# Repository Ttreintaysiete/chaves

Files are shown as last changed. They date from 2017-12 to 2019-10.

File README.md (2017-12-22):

# chaves
Cheap Hacky Audio/Video - Glitch VGA synth based on jonasbers.com/chav/

This is a WIP, and PCBs have not fully tested, if you want to contribute send a build to your favorite pcb provider and give us any feedback.

Pending...

* will generate a bom
* building guide

## Chaves

Its a glitch video synth bassed on CHA/V as stated, but with lots of controls and patcheable pins with the intentions of doing a mini-modular video glitch synth.

Like in the original CHA/V it has 6 VCOs, with selectables ranges, sync sources, frequency and effects outputs (thanks to the coupling caps). Here is a schematic of a single voice

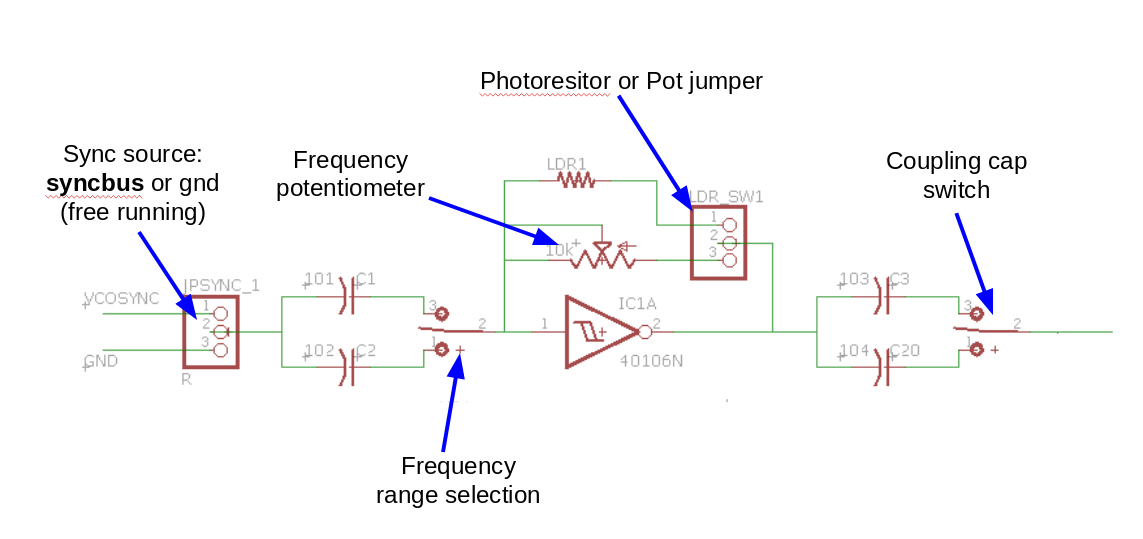
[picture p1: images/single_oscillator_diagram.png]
single oscillator schematic


* The __syncbus__ can be either connected to the vsyn or hsync of the VGA tester. This will send the selected sync to the jumperpins near the beggining of the Oscillator so you can either select each oscillator to be connected to this sync bus or not to be free running.
* Since we are using pinheaders you can use patcables from any point of the pcb so anthoer oscillator can __modulate__ the sync of a specific oscillator...
* Every voice output can be connected to any of the RGA VGA inputs with patchables, or can be patched somewhere else, to create complex patterns

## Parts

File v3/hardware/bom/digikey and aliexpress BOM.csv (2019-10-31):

description | qty | digikey | notes
9x 3×2 pin header row | 9 | 2057-PH2-06-UA-ND
2x 4×1 pin header row | 2 | PH1-04-UA
2x 1×12 pin header row | 2 | 2057-PH1-12-UA-ND
1x 1×9 pin header row | 1 | 2057-2PH1-09-UA-ND
2x blue LED | 2
4x 100K resistors (R6, R7, R9, R10) | 4 | https://www.digikey.ca/product-detail/en/stackpole-electronics-inc/CF14JT100K/CF14JT100KCT-ND/1830399
6x 1k resistors (R1, R2, R3, R4, R5, R8) | 6 | https://www.digikey.ca/product-detail/en/stackpole-electronics-inc/CF14JT1K00/CF14JT1K00CT-ND/1830350
2x BC547 npn transistor | 2 | BC547BTA
1x 4001 rectifier diode (D2) | 1 |  | optional
12x 4.7mm pitch spdt slide toggle switches (if you use flip-style instead, keep in mind that the pins will be inverted) | 12
6x 100k linear PC mount potentiometers | 6 | https://www.aliexpress.com/item/32986513037.html | choose 100k option
1x 40106 hex Schmitt IC | 1 | CD40106BE
1x 14-pin IC socket | 1
3x PJ302m 3.5mm jacks | 3 | https://www.aliexpress.com/item/32766726918.html | or (100 qty) | https://www.aliexpress.com/item/32765941321.html
2x LDR, a.k.a. photo-resistors (LDR1, LDR2) | 2 | https://www.digikey.ca/products/en/sensors-transducers/optical-sensors-photo-detectors-cds-cells/540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
11x (or more) 2.54mm closed jumpers | 11 | S9337-ND
10x (or more) 200mm socket-to-socket style jumper wires | 10 | 1568-1513-ND
4x 10uf electrolytic capacitors (C5, C15, C11, C23) negative leg should be pointing down. check oscillator 2 in the picture above. this part is not a joke: they could potentially explode if you put them in backwards. | 4 | https://www.digikey.ca/product-detail/en/panasonic-electronic-components/ECA-1HM100I/P10425CT-ND/8603345
4x 1uF ceramic capacitors (C4, C14, C10, C22) | 4 | FG28X5R1H105KRT06 | search if you want other footprints
13x 0.1 uF ceramic capacitors (C2, C20, C7, C17, C9, C21, C13, C25, C19) | 13 | SR215C104KAR
4x 0.01 uF ceramic capacitors (C3, C16, C18, C24) | 4 | K103K10X7RF5UH5
4x 1000 pF ceramic capacitors (C1, C6, C8, C12) | 4 | BC5111-ND

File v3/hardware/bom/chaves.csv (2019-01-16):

Qty | Value | Device | Package | Parts | Description
1 |  | DCBARRELPTH | DCJACK_2MM_PTH | CN1 | 2.0mm DC Barrel Jack
2 |  | LED5MM | LED5MM | LED1, LED2 | LED
8 |  | PINHD-1X1 | 1X01 | +5V, BJ, GJ, JGND, JHSYNC, JVCC1, JVSYNC, RJ | Pin header 1x1 for 0.1 spacing"
2 |  | PINHD-1X12-CB | 1X12-CB | O13, O45 | PIN HEADER
2 |  | PINHD-1X4 | 1X04 | JP2, JP13 | PIN HEADER
1 |  | PINHD-1X9 | 1X09-BIG | JP1 | Pin header 1x10 0.1 spacing"
9 |  | PINHD-2X3 | 2X03 | BLUE, GREEN, JP3, JP8, JP9, JP10, JP11, JP12, RED | PIN HEADER
2 |  | R-US_0204/2V | 0204V | LDR1, LDR2 | RESISTOR, American symbol
4 | 100k | R-US_0204/2V | 0204V | R6, R7, R9, R10 | RESISTOR, American symbol
4 | 101 | C-US050-025X075 | C050-025X075 | C1, C4, C10, C12 | CAPACITOR, American symbol
2 | 102 | C-US050-025X075 | C050-025X075 | C2, C5 | CAPACITOR, American symbol
8 | 103 | C-US050-025X075 | C050-025X075 | C3, C6, C8, C14, C16, C18, C22, C24 | CAPACITOR, American symbol
11 | 104 | C-US050-025X075 | C050-025X075 | C7, C9, C11, C13, C15, C17, C19, C20, C21, C23, C25 | CAPACITOR, American symbol
6 | 10k | POT_USVERTICAL | ALPS_POT_VERTICAL | POT1, POT2, POT3, POT4, POT5, POT6
1 | 1N4004 | 1N4004 | DO41-10 | D2 | DIODE
6 | 1k | R-US_0204/2V | 0204V | R1, R2, R3, R4, R5, R8 | RESISTOR, American symbol
1 | 40106N | 40106N | DIL14 | IC1 | Hex SCHMITT TRIGGER
3 | PJ302M | PJ302M | PJ302M | JIN1, JIN2, JIN3 | PJ302M horizontal / right angled mount 3.5 mm jack socket
12 | T-80-T-SPDT-ON-OFF-ON | T-80-T-SPDT-ON-OFF-ON | M9040P | U$1, U$2, U$3, U$4, U$5, U$6, U$7, U$8, U$9, U$10, U$11, U$12
2 | bc547 | -NPN-TO92-ECB | TO92-ECB | T1, T2 | NPN Transistror

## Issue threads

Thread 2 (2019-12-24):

Simultaneous audio and video output?

VicVID, 2019-12-24:
Hi - I am unsure if I am using the 9-pin header for the 3.5m output jacks correctly.  At present, I can out put audio OR video but not together.

Please advise!

Thanks

Vic   email:  randomaxe@cox.net

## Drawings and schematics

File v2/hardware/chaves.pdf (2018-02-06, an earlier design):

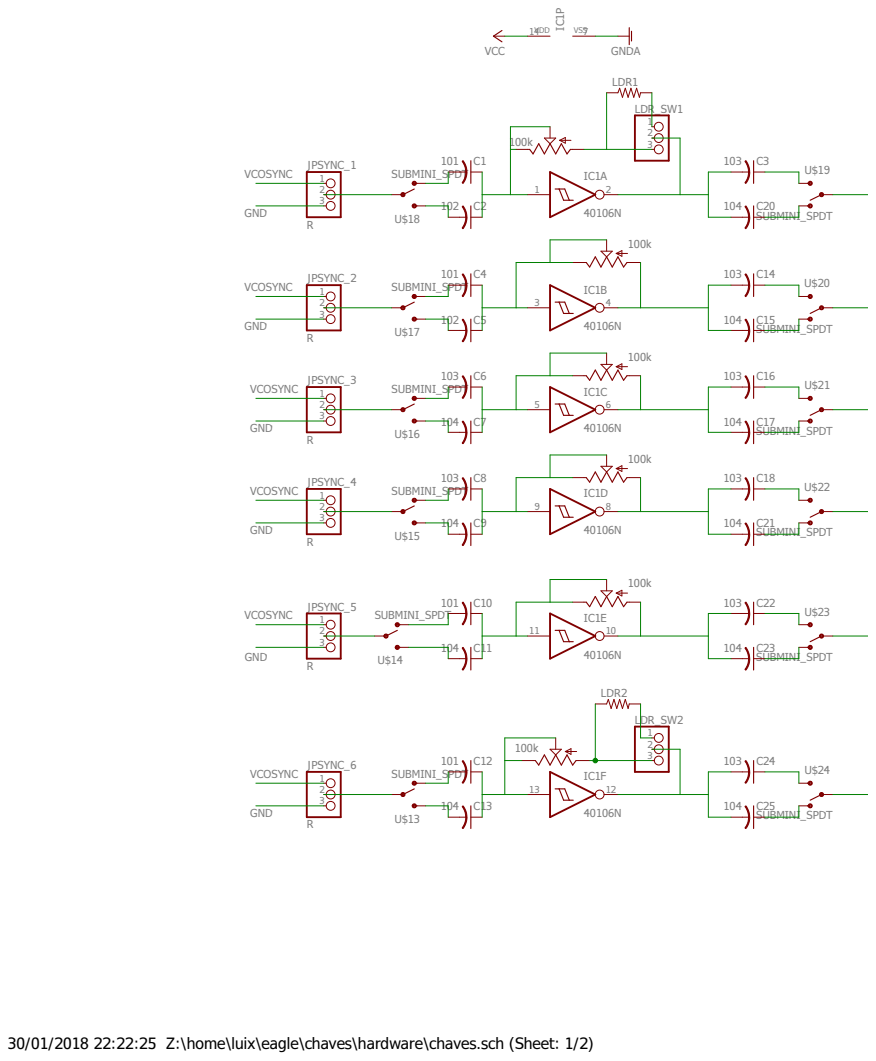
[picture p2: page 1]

30/01/2018 22:22:25 Z:\home\luix\eagle\chaves\hardware\chaves.sch (Sheet: 1/2)

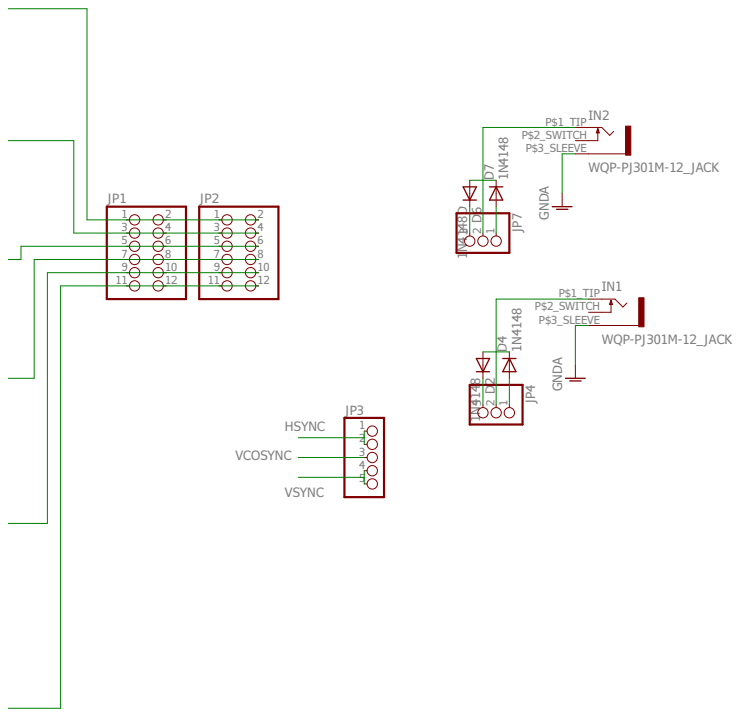
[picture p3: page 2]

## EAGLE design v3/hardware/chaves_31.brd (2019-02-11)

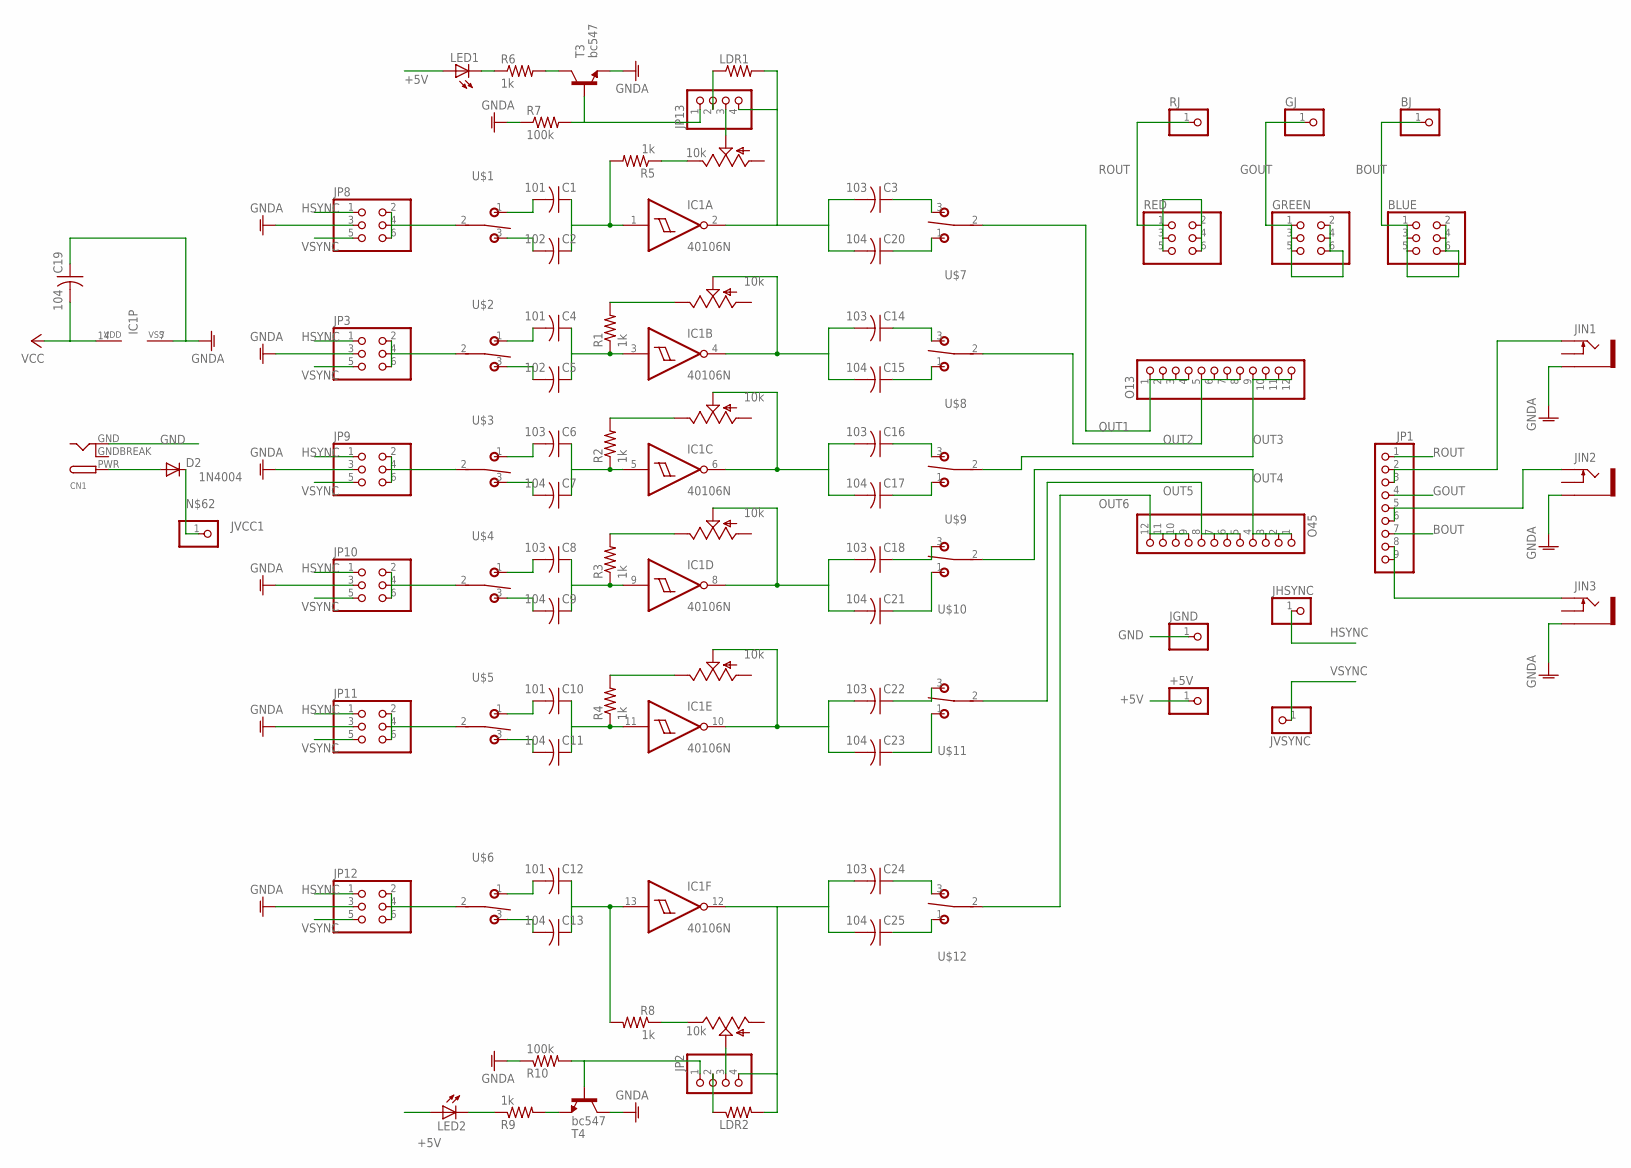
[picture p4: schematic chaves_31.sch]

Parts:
+5V: PINHD-1X1; 1X01
BJ: PINHD-1X1; 1X01
BLUE: PINHD-2X3; 2X03
C1, C4, C10, C12: 101; C050-025X075
C2, C5: 102; C050-025X075
C3, C6, C8, C14, C16, C18, C22, C24: 103; C050-025X075
C7, C9, C11, C13, C15, C17, C19, C20, C21, C23, C25: 104; C050-025X075
CN1: DCBARRELPTH; DCJACK_2MM_PTH
D2: 1N4004; DO41-10
GJ: PINHD-1X1; 1X01
GREEN: PINHD-2X3; 2X03
IC1: 40106N; DIL14
JGND: PINHD-1X1; 1X01
JHSYNC: PINHD-1X1; 1X01
JIN1, JIN2, JIN3: PJ302M
JP1: PINHD-1X9; 1X09-BIG
JP2, JP13: PINHD-1X4; 1X04
JP3, JP8, JP9, JP10, JP11, JP12: PINHD-2X3; 2X03
JVCC1: PINHD-1X1; 1X01
JVSYNC: PINHD-1X1; 1X01
LDR1, LDR2: R-US_0204/2V; 0204V
LED1, LED2: LED5MM
O13, O45: PINHD-1X12-CB; 1X12-CB
POT1, POT2, POT3, POT4, POT5, POT6: 10k; ALPS_POT_VERTICAL
R1, R2, R3, R4, R5, R6, R8, R9: 1k; 0204V
R7, R10: 100k; 0204V
RED: PINHD-2X3; 2X03
RJ: PINHD-1X1; 1X01
T3, T4: bc547; TO92-CBE
U$1, U$2, U$3, U$4, U$5, U$6, U$7, U$8, U$9, U$10, U$11, U$12: T-80-T-SPDT-ON-OFF-ON; M9040P

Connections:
+5V: +5V.1, C19.2, IC1.14 (VDD), LED1.A, LED2.A
BOUT: BJ.1, BLUE.1, BLUE.2, BLUE.3, BLUE.4, BLUE.5, BLUE.6, JP1.7
GND: C19.1, CN1.GND, IC1.7 (VSS), JGND.1, JIN1.GND (SLEEVE), JIN2.GND (SLEEVE), JIN3.GND (SLEEVE), JP3.3, JP8.3, JP9.3, JP10.3, JP11.3, JP12.3, R7.1, R10.1, T3.E, T4.C
GNDBREAK: CN1.GNDBREAK
GOUT: GJ.1, GREEN.1, GREEN.2, GREEN.3, GREEN.4, GREEN.5, GREEN.6, JP1.4
HSYNC: JHSYNC.1, JP3.1, JP8.1, JP9.1, JP10.1, JP11.1, JP12.1
unnamed: C1.2, U$1.1 (O)
unnamed: C2.2, U$1.3 (S)
unnamed: JP13.2, LDR1.1
unnamed: C5.2, U$2.3 (S)
unnamed: C4.2, U$2.1 (O)
unnamed: JP13.3, POT1.P$2 (S)
unnamed: C8.2, U$4.1 (O)
unnamed: C9.2, U$4.3 (S)
unnamed: JIN1.TIP, JP1.2, JP1.3
unnamed: C6.2, U$3.1 (O)
unnamed: C7.2, U$3.3 (S)
unnamed: JIN2.TIP, JP1.5, JP1.6
unnamed: JIN3.TIP, JP1.8, JP1.9
unnamed: JP3.2, JP3.4, JP3.6, U$2.2
unnamed: R6.2, T3.C
unnamed: C20.1, U$7.1 (O)
unnamed: C3.1, U$7.3 (S)
unnamed: LED1.K (C), R6.1
unnamed: POT1.P$1 (E), R5.1
unnamed: JP8.2, JP8.4, JP8.6, U$1.2
unnamed: LED2.K (C), R9.1
unnamed: POT2.P$1 (E), R1.2
unnamed: JP9.2, JP9.4, JP9.6, U$3.2
unnamed: C15.1, U$8.1 (O)
unnamed: R9.2, T4.E
unnamed: C14.1, U$8.3 (S)
unnamed: C17.1, U$9.1 (O)
unnamed: C16.1, U$9.3 (S)
unnamed: JP10.2, JP10.4, JP10.6, U$4.2
unnamed: JP13.1, R7.2, T3.B
unnamed: POT3.P$1 (E), R2.2
unnamed: JP11.2, JP11.4, JP11.6, U$5.2
unnamed: JP12.2, JP12.4, JP12.6, U$6.2
unnamed: C21.1, U$10.1 (O)
unnamed: C18.1, U$10.3 (S)
unnamed: C23.1, U$11.1 (O)
unnamed: C22.1, U$11.3 (S)
unnamed: C25.1, U$12.1 (O)
unnamed: C24.1, U$12.3 (S)
unnamed: C10.2, U$5.1 (O)
unnamed: POT4.P$1 (E), R3.2
unnamed: C11.2, U$5.3 (S)
unnamed: C13.2, U$6.3 (S)
unnamed: C12.2, U$6.1 (O)
unnamed: POT5.P$1 (E), R4.2
unnamed: C24.2, C25.2, IC1.12 (O), JP2.4, LDR2.2
unnamed: JP2.2, LDR2.1
unnamed: JP2.3, POT6.P$2 (S)
unnamed: POT6.P$1 (E), R8.1
unnamed: JP2.1, R10.2, T4.B
unnamed: D2.C, JVCC1.1
unnamed: C3.2, C20.2, IC1.2 (O), JP13.4, LDR1.2
unnamed: C14.2, C15.2, IC1.4 (O), POT2.P$2 (S)
unnamed: C16.2, C17.2, IC1.6 (O), POT3.P$2 (S)
unnamed: C18.2, C21.2, IC1.8 (O), POT4.P$2 (S)
unnamed: C22.2, C23.2, IC1.10 (O), POT5.P$2 (S)
OUT1: O13.1, O13.2, O13.3, O13.4, U$7.2
OUT2: O13.5, O13.6, O13.7, O13.8, U$8.2
OUT3: O13.9, O13.10, O13.11, O13.12, U$9.2
OUT4: O45.1, O45.2, O45.3, O45.4, U$10.2
OUT5: O45.5, O45.6, O45.7, O45.8, U$11.2
OUT6: O45.9, O45.10, O45.11, O45.12, U$12.2
ROUT: JP1.1, RED.1, RED.2, RED.3, RED.4, RED.5, RED.6, RJ.1
SS1: C1.1, C2.1, IC1.1 (I), R5.2
SS2: C4.1, C5.1, IC1.3 (I), R1.1
SS3: C6.1, C7.1, IC1.5 (I), R2.1
SS4: C8.1, C9.1, IC1.9 (I), R3.1
SS5: C10.1, C11.1, IC1.11 (I), R4.1
SS6: C12.1, C13.1, IC1.13 (I), R8.2
VIN: CN1.PWR, D2.A
VSYNC: JP3.5, JP8.5, JP9.5, JP10.5, JP11.5, JP12.5, JVSYNC.1

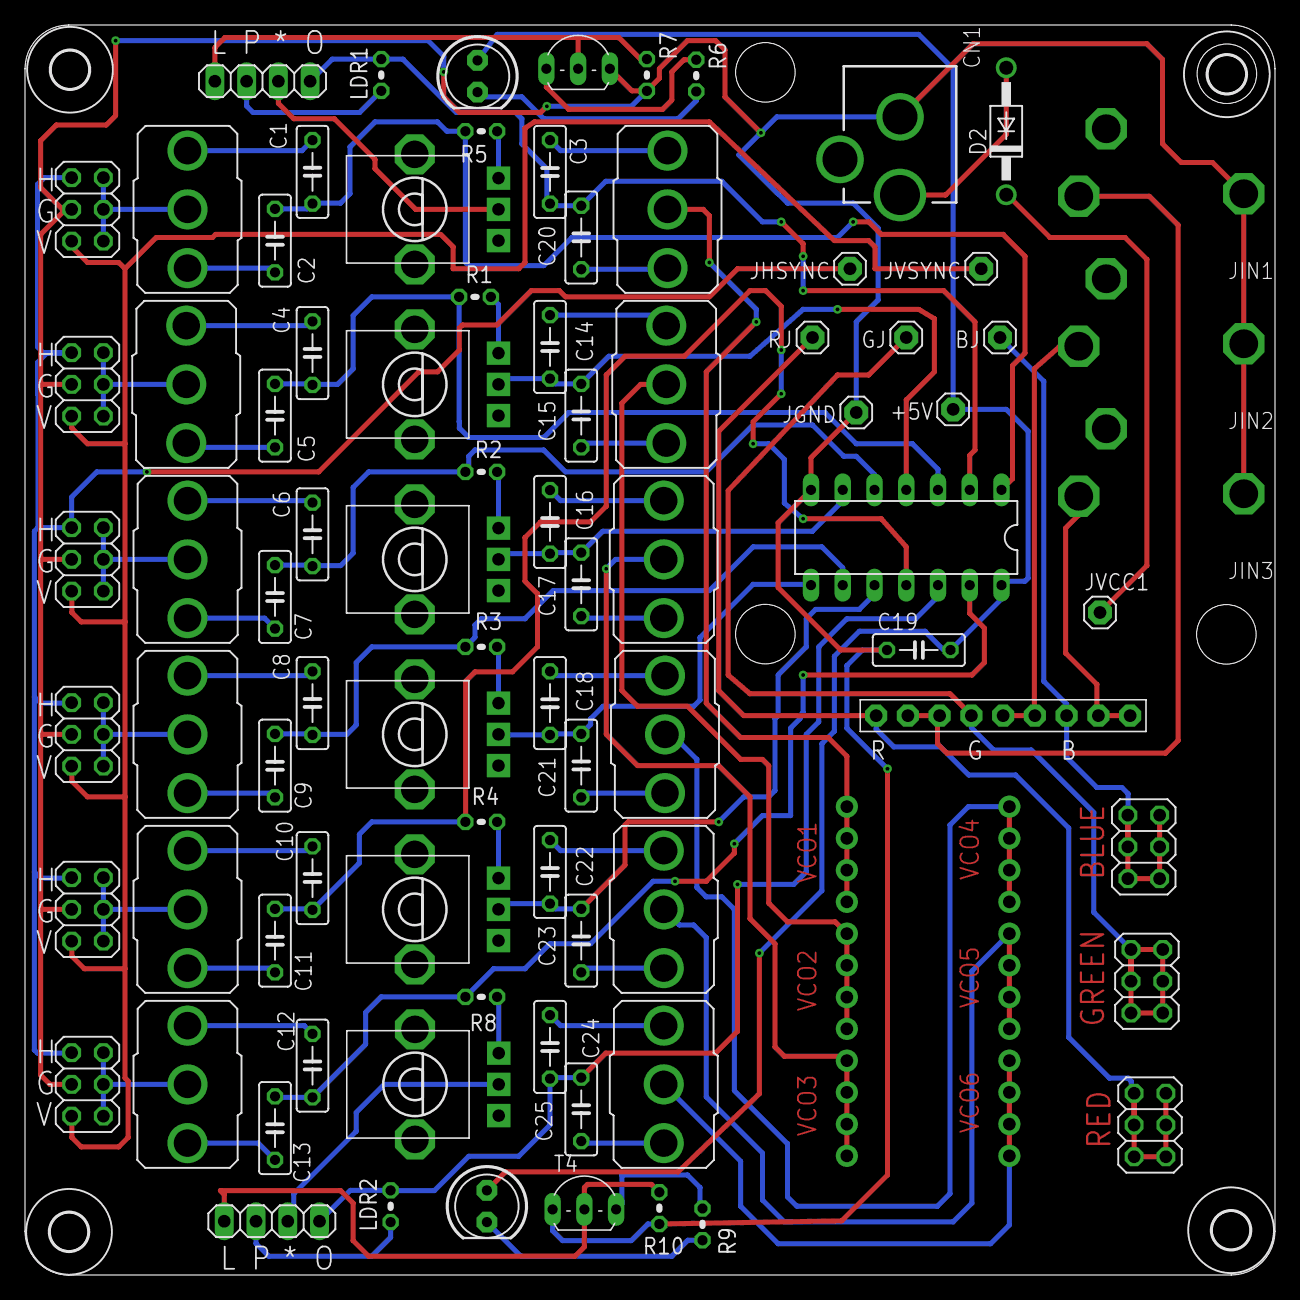
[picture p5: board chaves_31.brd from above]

Board: 2 copper layers, 100.0 x 100.0 mm, 95 parts (0 on the bottom side), 76 nets.

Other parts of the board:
E$1, E$2, E$3, E$4: DRILL_0.1875
E$5, E$6, E$7, E$8: 3,0

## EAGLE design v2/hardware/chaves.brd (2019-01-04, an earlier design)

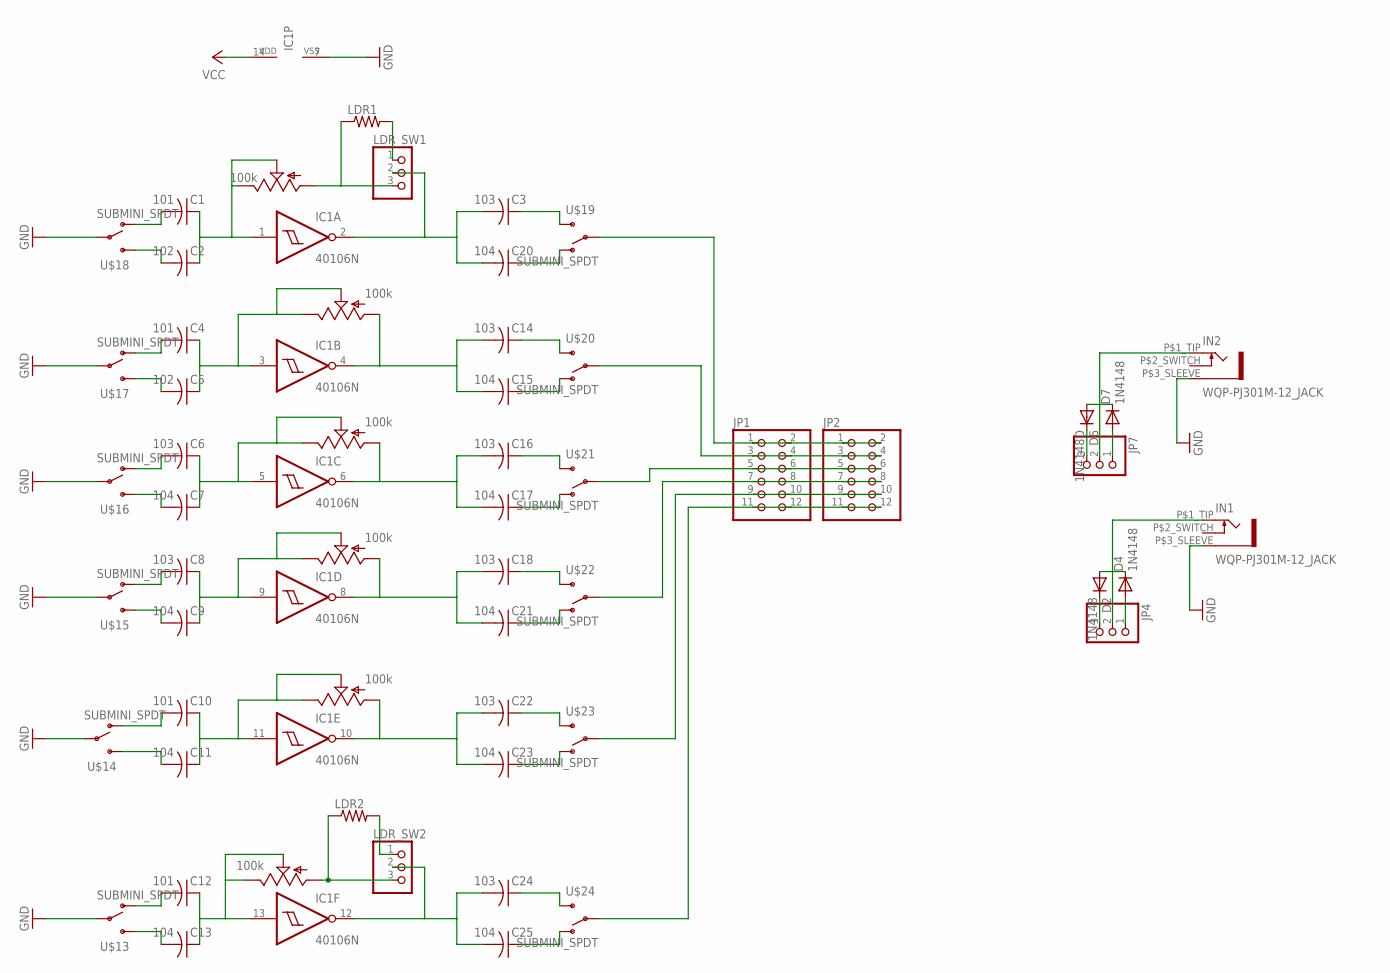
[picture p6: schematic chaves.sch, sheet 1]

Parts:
C1, C4, C10, C12: 101; C050-025X075
C2, C5: 102; C050-025X075
C3, C6, C8, C14, C16, C18, C22, C24: 103; C050-025X075
C7, C9, C11, C13, C15, C17, C20, C21, C23, C25: 104; C050-025X075
D2, D4, D7: 1N4148; DO35-7
D6: 1N4148D; DO35-7
IC1: 40106N; DIL14
IN1, IN2: WQP-PJ301M-12_JACK
JP1, JP2: PINHD-2X6; 2X06
JP4, JP7: PINHD-1X3CB; 1X03-CLEANBIG
LDR1, LDR2: R-US_0204/7; 0204/7
LDR_SW1, LDR_SW2: PINHD-1X3; 1X03
POT1, POT2, POT3, POT4, POT5, POT6: 100k; ALPS_POT_VERTICAL
U$13, U$14, U$15, U$16, U$17, U$18, U$19, U$20, U$21, U$22, U$23, U$24: SUBMINI_SPDT; SUBMINI_TOGGLE

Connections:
GND: IC1.7 (VSS), IN1.P$3_SLEEVE (1), IN2.P$3_SLEEVE (1), U$13.COM (COMMON), U$14.COM (COMMON), U$15.COM (COMMON), U$16.COM (COMMON), U$17.COM (COMMON), U$18.COM (COMMON); also elsewhere on the board
GND1: C3.2, C20.2, IC1.2 (O), LDR_SW1.2
GND2: C14.2, C15.2, IC1.4 (O), POT2.P$3 (A)
GND3: C16.2, C17.2, IC1.6 (O), POT3.P$3 (A)
GND4: C18.2, C21.2, IC1.8 (O), POT4.P$3 (A)
GND5: C22.2, C23.2, IC1.10 (O), POT5.P$3 (A)
GND6: C24.2, C25.2, IC1.12 (O), LDR_SW2.2
unnamed: C1.2, U$18.1 (O)
unnamed: C2.2, U$18.3 (S)
unnamed: LDR2.2, LDR_SW2.1
unnamed: C5.2, U$17.3 (S)
unnamed: C4.2, U$17.1 (O)
unnamed: LDR1.2, LDR_SW1.1
unnamed: C8.2, U$15.1 (O)
unnamed: C9.2, U$15.3 (S)
unnamed: D6.A, D7.C, IN2.P$1_TIP (2), JP7.2
unnamed: C6.2, U$16.1 (O)
unnamed: C7.2, U$16.3 (S)
unnamed: C20.1, U$19.1 (O)
unnamed: C3.1, U$19.3 (S)
unnamed: JP1.1, JP1.2, JP2.1, JP2.2, U$19.COM (COMMON)
unnamed: LDR1.1, LDR_SW1.3, POT1.P$3 (A)
unnamed: LDR2.1, LDR_SW2.3, POT6.P$3 (A)
unnamed: D2.A, D4.C, IN1.P$1_TIP (2), JP4.2
unnamed: C15.1, U$20.1 (O)
unnamed: C14.1, U$20.3 (S)
unnamed: JP1.3, JP1.4, JP2.3, JP2.4, U$20.COM (COMMON)
unnamed: C17.1, U$21.1 (O)
unnamed: C16.1, U$21.3 (S)
unnamed: JP1.5, JP1.6, JP2.5, JP2.6, U$21.COM (COMMON)
unnamed: C1.1, C2.1, IC1.1 (I), POT1.P$1 (E), POT1.P$2 (S)
unnamed: C4.1, C5.1, IC1.3 (I), POT2.P$1 (E), POT2.P$2 (S)
unnamed: C6.1, C7.1, IC1.5 (I), POT3.P$1 (E), POT3.P$2 (S)
unnamed: C8.1, C9.1, IC1.9 (I), POT4.P$1 (E), POT4.P$2 (S)
unnamed: C21.1, U$22.1 (O)
unnamed: C18.1, U$22.3 (S)
unnamed: JP1.7, JP1.8, JP2.7, JP2.8, U$22.COM (COMMON)
unnamed: C23.1, U$23.1 (O)
unnamed: C22.1, U$23.3 (S)
unnamed: JP1.9, JP1.10, JP2.9, JP2.10, U$23.COM (COMMON)
unnamed: C25.1, U$24.1 (O)
unnamed: C24.1, U$24.3 (S)
unnamed: JP1.11, JP1.12, JP2.11, JP2.12, U$24.COM (COMMON)
unnamed: C10.2, U$14.1 (O)
unnamed: C10.1, C11.1, IC1.11 (I), POT5.P$1 (E), POT5.P$2 (S)
unnamed: C11.2, U$14.3 (S)
unnamed: C13.2, U$13.3 (S)
unnamed: C12.2, U$13.1 (O)
unnamed: C12.1, C13.1, IC1.13 (I), POT6.P$1 (E), POT6.P$2 (S)
unnamed: D2.C, JP4.3
unnamed: D4.A, JP4.1
unnamed: D6.C, JP7.3
unnamed: D7.A, JP7.1
VCC: IC1.14 (VDD); also elsewhere on the board

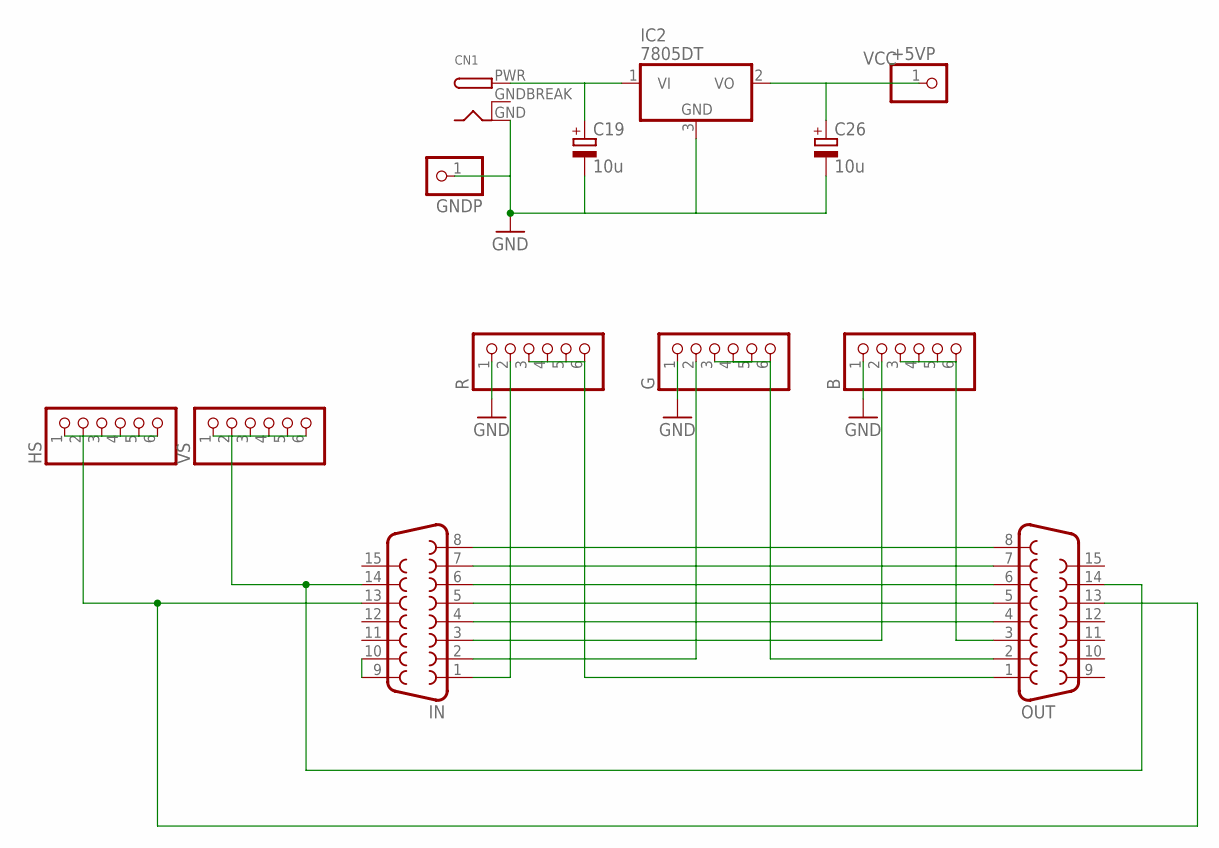
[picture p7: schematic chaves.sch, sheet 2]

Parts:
+5VP: PINHD-1X1CB; 1X01-CLEANBIG
B: PINHD-1X6CLEAN; 1X06-CLEAN
C19, C26: 10u; E2,5-5
CN1: DCBARRELPTH; DCJACK_2MM_PTH
G: PINHD-1X6CLEAN; 1X06-CLEAN
GNDP: PINHD-1X1CB; 1X01-CLEANBIG
HS: PINHD-1X6CLEAN; 1X06-CLEAN
IC2: 7805DT; TO252
IN: F15HDH; HDF15H
OUT: F15HDH; HDF15H
R: PINHD-1X6CLEAN; 1X06-CLEAN
VS: PINHD-1X6CLEAN; 1X06-CLEAN

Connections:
GND: B.1, C19.-, C26.-, CN1.GND, G.1, GNDP.1, IC2.3 (GND), IN.4, IN.5, IN.6, IN.7, IN.8, IN.9, IN.10, OUT.4, OUT.5, OUT.6, OUT.7, OUT.8, R.1; also elsewhere on the board
GNDBREAK: CN1.GNDBREAK
unnamed: IN.1, R.2
unnamed: OUT.1, R.3, R.4, R.5, R.6
unnamed: G.2, IN.2
unnamed: G.3, G.4, G.5, G.6, OUT.2
unnamed: B.2, IN.3
unnamed: B.3, B.4, B.5, B.6, OUT.3
unnamed: IN.14, OUT.14, VS.1, VS.2, VS.3, VS.4, VS.5, VS.6
unnamed: HS.1, HS.2, HS.3, HS.4, HS.5, HS.6, IN.13, OUT.13
unnamed: C19.+, CN1.PWR, IC2.1 (VI)
VCC: +5VP.1, C26.+, IC2.2 (VO); also elsewhere on the board

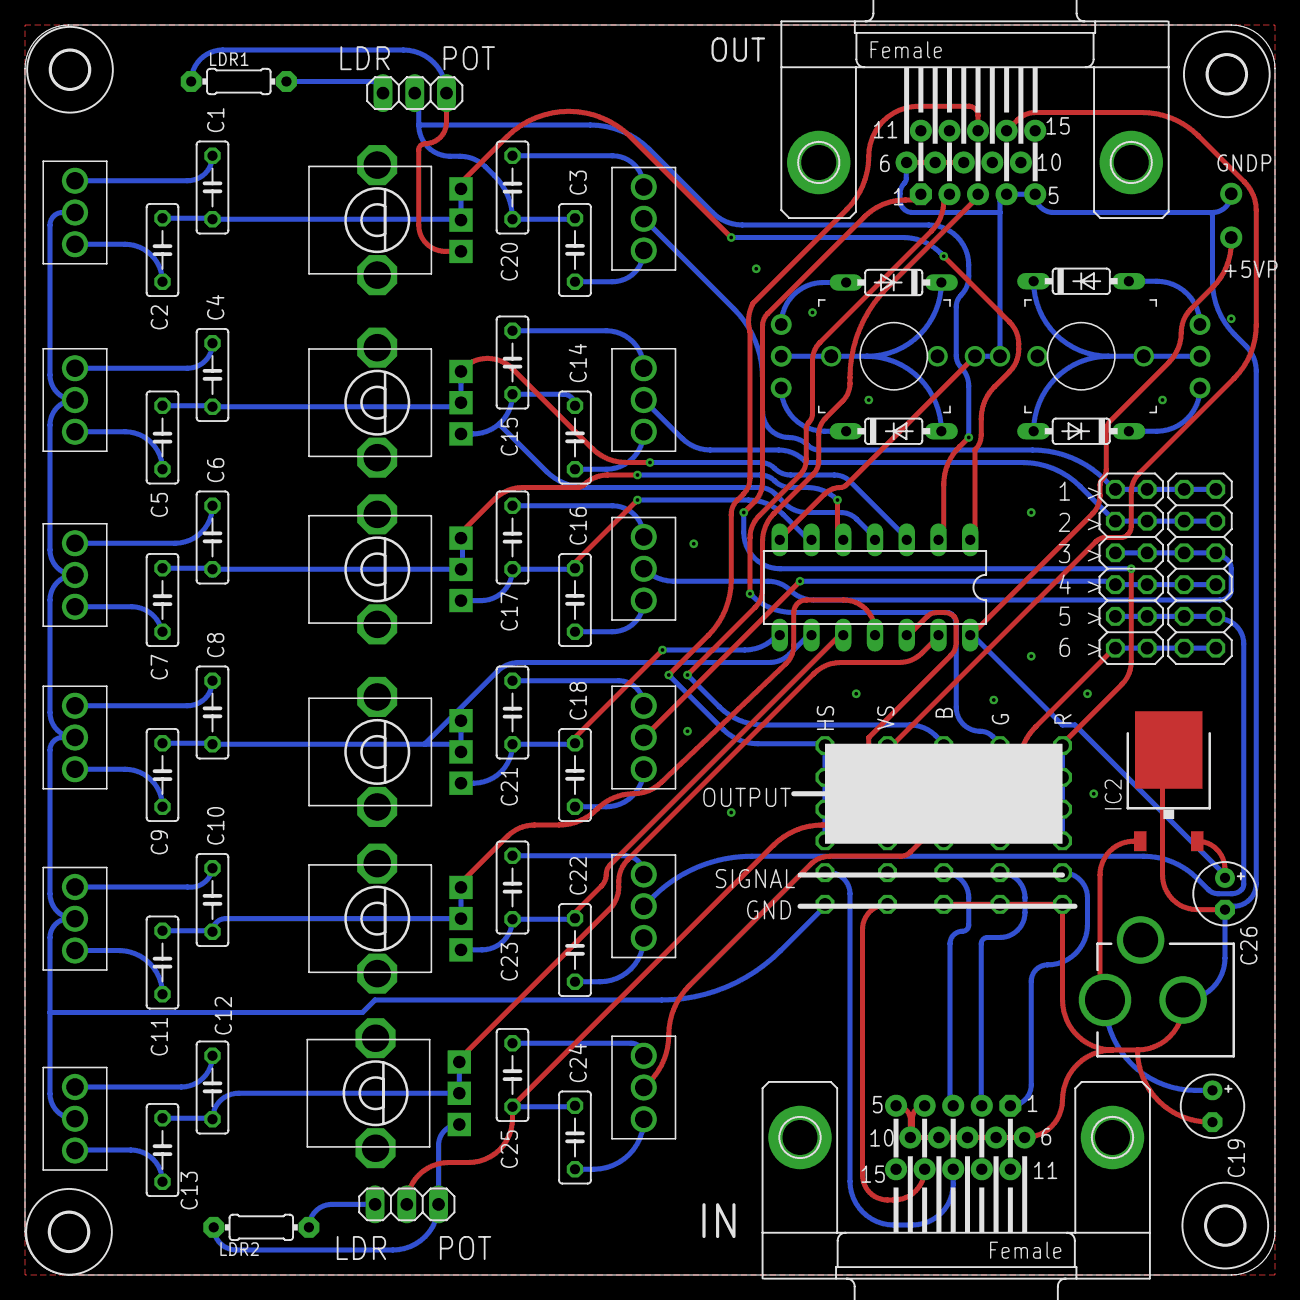
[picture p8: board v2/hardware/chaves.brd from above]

Board: 2 copper layers, 100.0 x 100.0 mm, 74 parts (0 on the bottom side), 63 nets.

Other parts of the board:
E$1, E$5, E$7, E$8: 3,0

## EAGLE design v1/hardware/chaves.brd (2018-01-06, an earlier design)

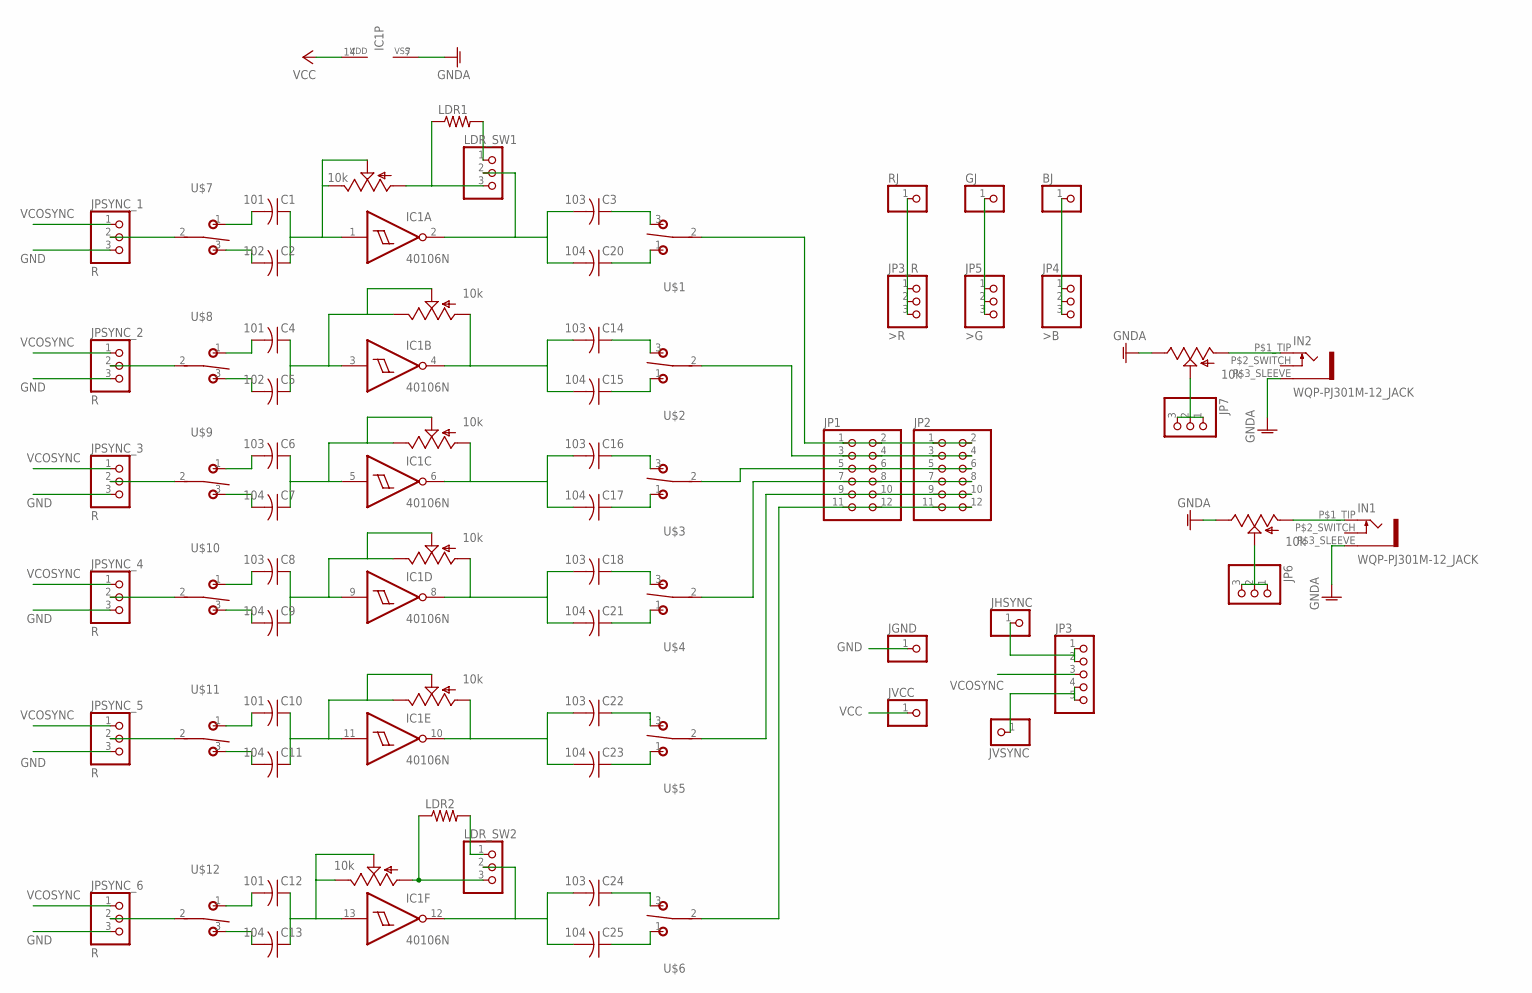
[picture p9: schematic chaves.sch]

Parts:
BJ: PINHD-1X1; 1X01
C1, C4, C10, C12: 101; C050-025X075
C2, C5: 102; C050-025X075
C3, C6, C8, C14, C16, C18, C22, C24: 103; C050-025X075
C7, C9, C11, C13, C15, C17, C20, C21, C23, C25: 104; C050-025X075
GJ: PINHD-1X1; 1X01
IC1: 40106N; DIL14
IN1, IN2: WQP-PJ301M-12_JACK
JGND: PINHD-1X1; 1X01
JHSYNC: PINHD-1X1; 1X01
JP1, JP2: PINHD-2X6; 2X06
JP3: PINHD-1X5; 1X05
JP3_R: >R; 1X03
JP4: >B; 1X03
JP5: >G; 1X03
JP6, JP7: PINHD-1X3CB; 1X03-CLEANBIG
JPSYNC_1, JPSYNC_2, JPSYNC_3, JPSYNC_4, JPSYNC_5, JPSYNC_6: R; 1X03
JVCC: PINHD-1X1; 1X01
JVSYNC: PINHD-1X1; 1X01
LDR1, LDR2: R-US_0204/7; 0204/7
LDR_SW1, LDR_SW2: PINHD-1X3; 1X03
POT1, POT2, POT3, POT4, POT5, POT6, POT7, POT8: 10k; ALPS_POT_VERTICAL
RJ: PINHD-1X1; 1X01
U$1, U$2, U$3, U$4, U$5, U$6, U$7, U$8, U$9, U$10, U$11, U$12: T-80-T-SPDT-ON-OFF-ON; M9040P

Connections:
GND: IC1.7 (VSS), IN1.P$3_SLEEVE (1), IN2.P$3_SLEEVE (1), JGND.1, JPSYNC_1.3, JPSYNC_2.3, JPSYNC_3.3, JPSYNC_4.3, JPSYNC_5.3, JPSYNC_6.3, POT7.P$1 (E), POT8.P$1 (E)
GND1: C3.2, C20.2, IC1.2 (O), LDR_SW1.2
GND2: C14.2, C15.2, IC1.4 (O), POT2.P$3 (A)
GND3: C16.2, C17.2, IC1.6 (O), POT3.P$3 (A)
GND4: C18.2, C21.2, IC1.8 (O), POT4.P$3 (A)
GND5: C22.2, C23.2, IC1.10 (O), POT5.P$3 (A)
GND6: C24.2, C25.2, IC1.12 (O), LDR_SW2.2
unnamed: C1.2, U$7.1 (O)
unnamed: C2.2, U$7.3 (S)
unnamed: LDR2.2, LDR_SW2.1
unnamed: C5.2, U$8.3 (S)
unnamed: C4.2, U$8.1 (O)
unnamed: LDR1.2, LDR_SW1.1
unnamed: C8.2, U$10.1 (O)
unnamed: C9.2, U$10.3 (S)
unnamed: IN2.P$1_TIP (2), POT8.P$3 (A)
unnamed: C6.2, U$9.1 (O)
unnamed: C7.2, U$9.3 (S)
unnamed: JP6.1, JP6.2, JP6.3, POT7.P$2 (S)
unnamed: BJ.1, JP4.1, JP4.2, JP4.3
unnamed: GJ.1, JP5.1, JP5.2, JP5.3
unnamed: JP3_R.1, JP3_R.2, JP3_R.3, RJ.1
unnamed: C20.1, U$1.1 (O)
unnamed: C3.1, U$1.3 (S)
unnamed: JP1.1, JP1.2, JP2.1, JP2.2, U$1.2
unnamed: LDR1.1, LDR_SW1.3, POT1.P$3 (A)
unnamed: JHSYNC.1, JP3.1, JP3.2
unnamed: JP3.4, JP3.5, JVSYNC.1
unnamed: LDR2.1, LDR_SW2.3, POT6.P$3 (A)
unnamed: IN1.P$1_TIP (2), POT7.P$3 (A)
unnamed: C15.1, U$2.1 (O)
unnamed: JP7.1, JP7.2, JP7.3, POT8.P$2 (S)
unnamed: C14.1, U$2.3 (S)
unnamed: JP1.3, JP1.4, JP2.3, JP2.4, U$2.2
unnamed: C17.1, U$3.1 (O)
unnamed: C16.1, U$3.3 (S)
unnamed: JP1.5, JP1.6, JP2.5, JP2.6, U$3.2
unnamed: C1.1, C2.1, IC1.1 (I), POT1.P$1 (E), POT1.P$2 (S)
unnamed: C4.1, C5.1, IC1.3 (I), POT2.P$1 (E), POT2.P$2 (S)
unnamed: C6.1, C7.1, IC1.5 (I), POT3.P$1 (E), POT3.P$2 (S)
unnamed: C8.1, C9.1, IC1.9 (I), POT4.P$1 (E), POT4.P$2 (S)
unnamed: C21.1, U$4.1 (O)
unnamed: C18.1, U$4.3 (S)
unnamed: JP1.7, JP1.8, JP2.7, JP2.8, U$4.2
unnamed: C23.1, U$5.1 (O)
unnamed: C22.1, U$5.3 (S)
unnamed: JP1.9, JP1.10, JP2.9, JP2.10, U$5.2
unnamed: C25.1, U$6.1 (O)
unnamed: C24.1, U$6.3 (S)
unnamed: JP1.11, JP1.12, JP2.11, JP2.12, U$6.2
unnamed: C10.2, U$11.1 (O)
unnamed: C10.1, C11.1, IC1.11 (I), POT5.P$1 (E), POT5.P$2 (S)
unnamed: C11.2, U$11.3 (S)
unnamed: C13.2, U$12.3 (S)
unnamed: C12.2, U$12.1 (O)
unnamed: C12.1, C13.1, IC1.13 (I), POT6.P$1 (E), POT6.P$2 (S)
SS1: JPSYNC_1.2, U$7.2
SS2: JPSYNC_2.2, U$8.2
SS3: JPSYNC_3.2, U$9.2
SS4: JPSYNC_4.2, U$10.2
SS5: JPSYNC_5.2, U$11.2
SS6: JPSYNC_6.2, U$12.2
VCC: IC1.14 (VDD), JVCC.1
VCOSYNC: JP3.3, JPSYNC_1.1, JPSYNC_2.1, JPSYNC_3.1, JPSYNC_4.1, JPSYNC_5.1, JPSYNC_6.1

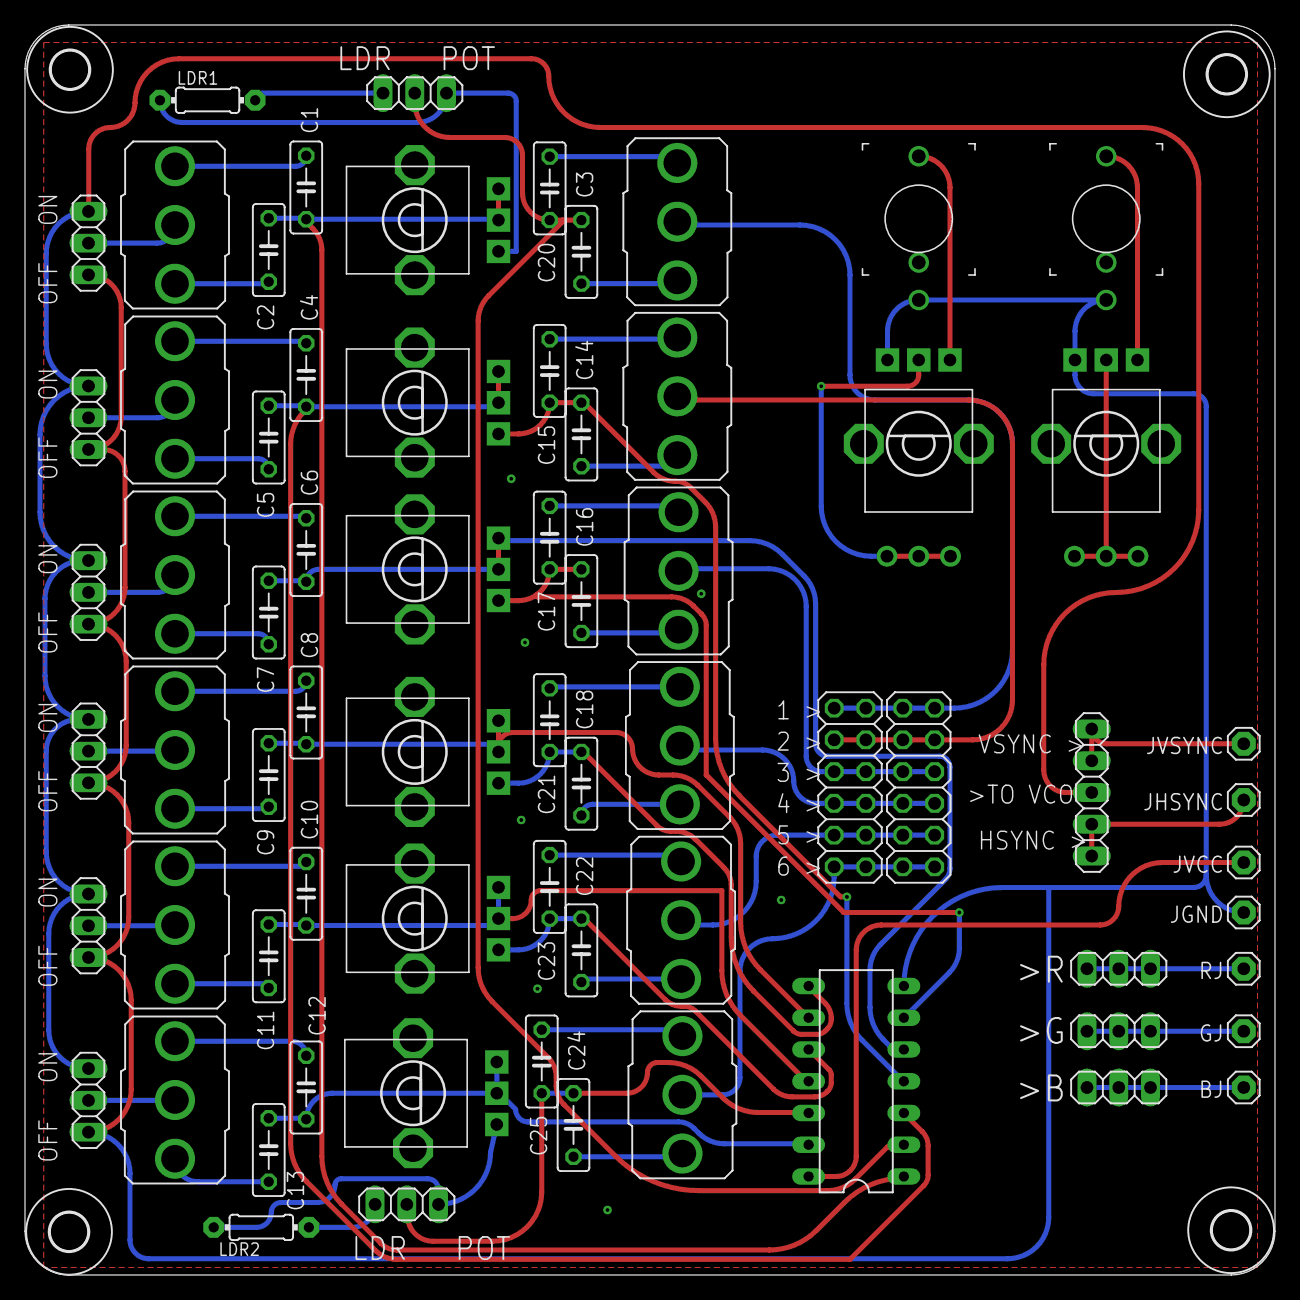
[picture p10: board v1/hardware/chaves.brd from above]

Board: 2 copper layers, 100.0 x 100.0 mm, 76 parts (0 on the bottom side), 64 nets.

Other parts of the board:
E$5, E$6, E$7, E$8: 3,0

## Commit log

2017-12-13 Initial commit with gerber files
    [chaves.brd, chaves.sch, vgasyncboard.brd]
2017-12-13 Adding fixed texts layers
    [chaves.brd]
2017-12-22 Updating schematic pdf and adding single voice diagram
2018-01-06 all done except ground plane
    [chaves.brd, chaves.sch]
2018-01-06 Ground planed
    [chaves.brd, chaves.sch]
2018-02-06 new version of chaves
    [chaves.brd, chaves.sch, vgasyncboard.brd]
2018-02-06 moving old bom
2018-12-08 Rename and adding v3
    [chaves.brd, chaves.sch, vgasyncboard.brd]
2018-12-08 working on position board v3
    [chaves.brd]
2018-12-08 minor fixes on text and aligment
    [chaves.brd]
2018-12-08 changing pinheaders to connect the trigger in properly
    [chaves.brd, chaves.sch]
2019-01-02 Finixhed position and merged pins
    [chaves.brd, chaves.sch]
2019-01-02 fully routed v3, checked errors, layers corrected ready to fav proto
    [chaves.brd, chaves.sch]
2019-01-04 Revised gerbers for all versions
    [chaves.brd, chaves.sch]
2019-01-12 Adding updated gerbers
    [chaves.brd]
2019-01-16 Adding v3 bom
    [chaves.csv]
2019-02-11 renaming for versions
    [chaves_30.brd, chaves_30.sch]
2019-02-11 Adding gerbers for 31 version, fixed many problems of the 3.0: - there was an overlap on the VCO1 feedback line - added a current limiting resistor of 1k - removed the 100k resistors from the voltage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
    [chaves_31.brd, chaves_31.sch]
2019-10-31 Add digikey/aliexpress BOM (untested at the moment)
    [digikey and aliexpress BOM.csv]
